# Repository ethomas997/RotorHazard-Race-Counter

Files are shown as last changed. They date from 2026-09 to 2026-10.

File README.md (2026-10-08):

# RotorHazard Race Counter

A battery-friendly ePaper sign that shows the current **heat** and **race number** at the flight line, so
pilots and spectators can always tell which race is up. Designed and built by RocketSled.

The display is a Seeed XIAO ESP32-C3 driving a 5.83" 648×480 monochrome ePaper panel in a 3D-printed
housing with two push-buttons (DN / UP). It can be run standalone from the buttons, or over WiFi from a
small built-in web page and HTTP API – or, given the address of a [RotorHazard](https://github.com/RotorHazard/RotorHazard)
timer, it follows the timer's current heat and round by itself.

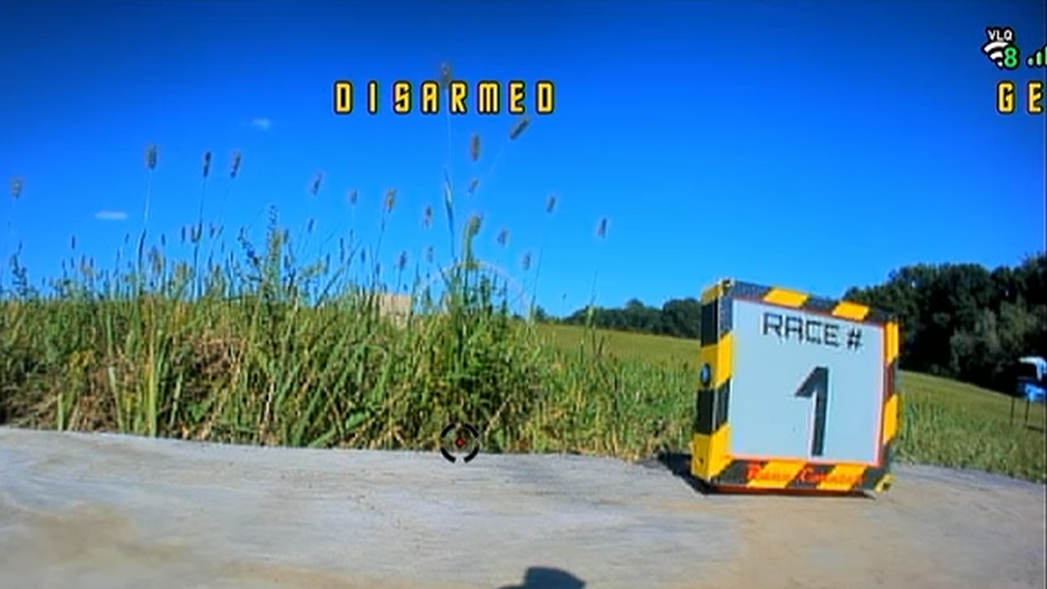
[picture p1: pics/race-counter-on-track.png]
Race Counter on the track


## Repository layout

| Path | Contents |
|---|---|
| `firmware/RaceCounter/` | Arduino sketch (RocketSled's V2.0 of Aug 9 2026, plus the fixes listed in `git log`), as modules: `RaceCounter.ino` (`setup`/`loop`), `RaceCounter.h` (config + shared state), `display.h/.cpp` (ePaper drawing), `web.h/.cpp` (web UI / HTTP API), `wifi_config.h/.cpp` (WiFi, setup AP, credentials, standalone mode), `buttons.h/.cpp`, `rh_client.h/.cpp` (follows a RotorHazard timer) |
| `firmware/RaceCounter/sketch.yaml` | Board / partition / option settings, read by arduino-cli and Arduino IDE 2.2+ |
| `firmware/RaceCounter/bg_png.h` | Web-page background image (RotorHazard logo) embedded as a byte array; regenerate with `tools/bin2header.py` |
| `firmware/RaceCounter/driver.h` | Seeed_GFX hardware selection (board + panel). **Required** – see Building |
| `firmware/libraries/` | Git submodules, pinned: `Seeed_GFX` (display), `WebSockets` (Socket.IO client), `ArduinoJson` |
| `docs/parts-list.md` | Bill of materials |
| `pics/` | Photos of the built unit and screenshots of the web pages |
| `stl/` | 3D-printed housing models (STL); see [Enclosure](#enclosure-3d-printing) |
| `assets/` | Source font (Orbitron Bold, OFL) and logo images used to generate the `.h` bitmaps |
| `tools/bin2header.py` | Turns a binary file into a `PROGMEM` C array header |

## Hardware

* Seeed Studio **XIAO ESP32-C3**
* Seeed **ePaper Driver Board for XIAO** (V2) – 24-pin FPC, JST battery input with charge IC
* **5.83" monochrome ePaper**, 648×480, UC8179 controller, 24-pin FPC
* Two momentary push-buttons to GND: **DN → D5**, **UP → D6** (internal pull-ups)
* 18650 Li-ion cell with a latching power button; USB-C pass-through port for charging and programming
* 3D-printed housing — STL files in [`stl/`](stl/) (see [Enclosure](#enclosure-3d-printing))

Full list with links: [docs/parts-list.md](docs/parts-list.md).

| Front | Inside |
|---|---|
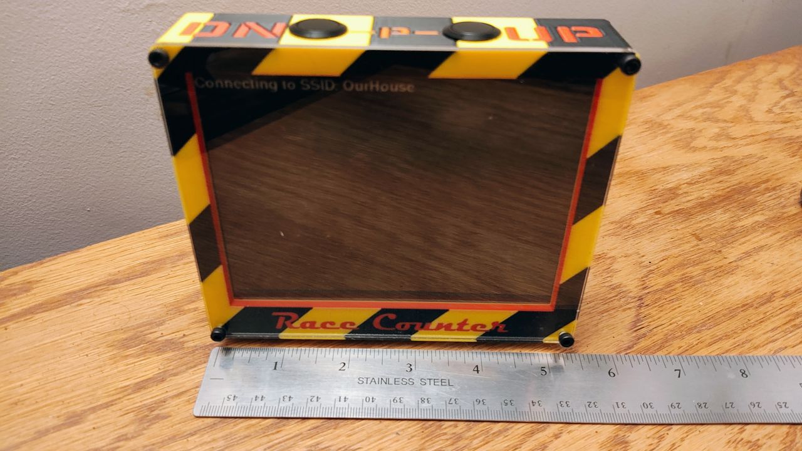
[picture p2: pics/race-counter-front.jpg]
Front
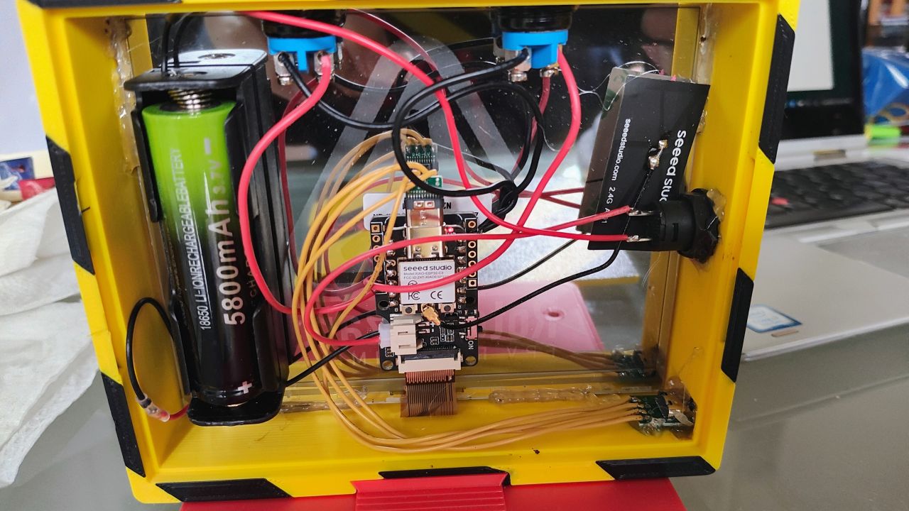
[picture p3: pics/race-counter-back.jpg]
Inside, back plate off
|  |  |

## Enclosure (3D printing)

The housing was designed by RocketSled. The STL files are in [`stl/`](stl/):

| File | Part |
|---|---|
| `Race Counter r2.stl` | Main body / front bezel |
| `Race Counter Back r3.stl` | Back cover |
| `Race Counter Base r2.stl` | Base / stand |

The geometry is split into sections so the unit can be printed in the colors shown in the photos, but
**the STLs do not carry any color information** — that is multi-material data specific to the printer, and
the colored-in version is only usable on a Bambu Lab H2C (multi-color) printer. On any other printer the
parts print in a single color; to reproduce the two-tone look you assign colors to the sections yourself in
your slicer.

## Building the firmware

RocketSled builds with Visual Studio + VisualMicro; the sketch also builds in the Arduino IDE 2.x and with
`arduino-cli`. Verified 2026-09-20 with `arduino-cli` 0.35.2, esp32 core 3.3.8, Seeed_GFX 2.0.3
(commit `0dfdd71`), WebSockets 2.7.3 and ArduinoJson 7.4.2:

```
Sketch uses 1510517 bytes (48%) of program storage space. Maximum is 3145728 bytes.
Global variables use 39152 bytes (11%) of dynamic memory.
```

The board and options are recorded in `firmware/RaceCounter/sketch.yaml`, which arduino-cli and Arduino
IDE 2.2+ pick up automatically, so the command line is just:

```bash
arduino-cli compile --libraries firmware/libraries firmware/RaceCounter
```

1. **Board package:** *esp32 by Espressif Systems* (RocketSled used 3.3.8; board-manager URL
   `https://espressif.github.io/arduino-esp32/package_esp32_index.json`). Board: **XIAO_ESP32C3**.
   * Partition Scheme: **Huge APP (3MB No OTA/1MB SPIFFS)** – the sketch filled 95 % of the default
     scheme's 1.2 MB app slot, and the device doesn't use OTA, so the larger no-OTA layout costs nothing.
     (RocketSled's units were flashed with the *Default 4MB* scheme; re-flashing with this one is fine – the
     partition table is rewritten as part of the upload.)
   * USB CDC On Boot: **Enabled**
2. **Libraries:** **[Seeed_GFX](https://github.com/Seeed-Studio/Seeed_GFX)** (display; not in the Arduino
   Library Manager), **[WebSockets](https://github.com/Links2004/arduinoWebSockets)** (Socket.IO client) and
   **[ArduinoJson](https://arduinojson.org/)** are vendored as git submodules under `firmware/libraries/`,
   pinned to versions known to build. Get them with
   ```bash
   git submodule update --init
   ```
   (or clone with `--recurse-submodules`). Then make them visible to the Arduino IDE by linking or copying
   each into your sketchbook's `libraries` folder – on Windows a directory junction avoids a second copy:
   ```
   mklink /J "<sketchbook>\libraries\Seeed_GFX" "<repo>\firmware\libraries\Seeed_GFX"
   ```
   (and likewise for `WebSockets` and `ArduinoJson`). `arduino-cli` users can skip the links and pass
   `--libraries firmware/libraries` instead.

   Seeed_GFX is a fork of TFT_eSPI and **conflicts with TFT_eSPI / Adafruit_GFX – remove those from your
   `libraries` folder first.** The sketch will still compile against the wrong library, it just won't drive
   the panel.
3. **`driver.h`** must be in the sketch folder (it is). Seeed_GFX picks it up automatically:
   ```c
   #define BOARD_SCREEN_COMBO 503   // 5.83 inch monochrome ePaper (UC8179), 648x480
   #define USE_XIAO_EPAPER_DRIVER_BOARD
   ```
   If you change the panel or carrier board, regenerate this with Seeed's configuration tool.
4. Compile and upload the sketch over USB-C. That's it – there is no separate filesystem image to upload;
   the web page's background image is compiled into the firmware (`bg_png.h`).

All other libraries (`WiFi`, `WebServer`, `HTTPClient`, `Preferences`) ship with the esp32 core.

## Operation

### First power-up / WiFi setup

* With no saved credentials the device starts an open access point **`RaceCounter-Setup`** and shows the AP
  IP (`192.168.4.1`) and MAC on the panel. Connect to it, open `http://192.168.4.1`, enter your SSID and
  password, *Save & Reboot*.
* It then connects to that network, shows the IP it was given and its MAC for a few seconds, and displays
  the RotorHazard splash screen. The web interface is at `http://<ip>/`.
* Every startup / status text screen has the name and firmware version on its first line.
* The MAC shown on both the AP screen and the "Connected" screen is the station MAC – the one your router
  sees – so it can be used directly for a static DHCP lease.

### Buttons

| Action | Result | Timing |
|---|---|---|
| UP | race number +1 (1…99, wraps) | Acts the moment the button is released, or after 0.25 s if it is held. Keep holding and it keeps stepping, one step per panel refresh (every 2–4 s). |
| DN | race number −1 (1…99, wraps) | Same as UP. Does nothing while the splash screen is showing. |
| UP or DN on a PRACTICE screen | leave practice: the big-"P" screen goes back to the race count, the "PRACTICE over a round number" screen switches its banner to "RACE #" – the number is not changed either way | |
| UP + DN together (short), in normal operation | toggle **PRACTICE** mode | The second button must go down within 0.25 s of the first; acts when either is released (before 3 s). |
| UP + DN **held for 3 s** | show the **information screen**: mode, SSID, IP, web address, signal, MAC, what was being shown, uptime, free memory | Acts at 3 s while both are still down. Any button press on the information screen goes back to the previous screen (splash / race count / practice) without changing anything. |
| UP + DN held at power-on | erase saved WiFi credentials and standalone flag, restart into AP mode | The pins are read **once**, about 2–3 s after power-on. Hold both before switching on, keep holding until "Old SSID and password deleted…" appears, then release. |
| UP + DN while "Connecting to SSID…" | same – use this if it is stuck on a network it can't reach | Checked every 0.3 s while connecting; any simultaneous press of ≥ 0.3 s works. |
| UP + DN while in AP mode | short: enable **standalone mode** (no WiFi, buttons only) and restart; long: information screen | Same detection as above. To leave standalone mode, use the power-on hold. |

Heat number can only be set from the web interface / HTTP API.

### Web interface

The main page shows what the panel is currently displaying, and has −/+ and *Set* controls for Heat and Race,
a *Practice* toggle, *Reset*, and *Refresh* (re-reads the current state from the counter), with the firmware
version at the bottom. The 🛠 icon
top-right opens the settings page where the SSID/password can be changed (*Update*) or erased (*Clear*);
both reboot the device. The settings page also has the **RotorHazard** server field (below) and shows the MAC
address and firmware version (`FW_VERSION` in `RaceCounter.h`, also printed in the serial banner at boot).

| Main page | Settings page |
|---|---|
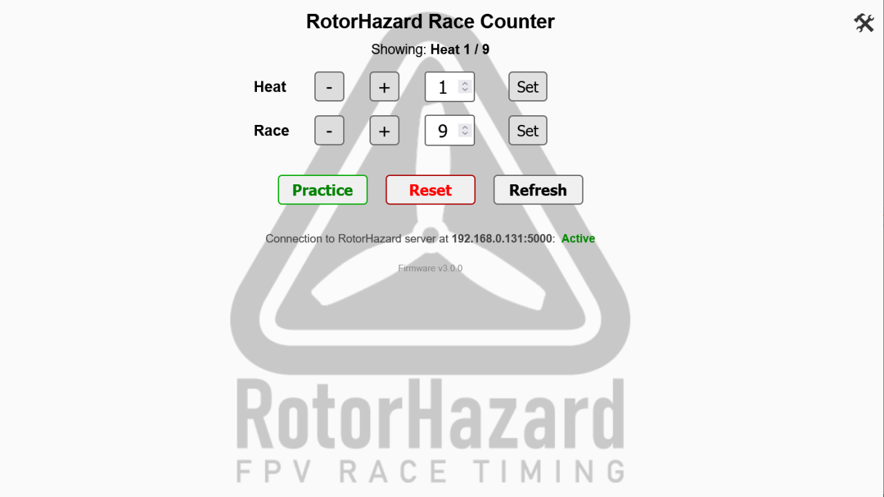
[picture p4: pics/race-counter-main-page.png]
Main page
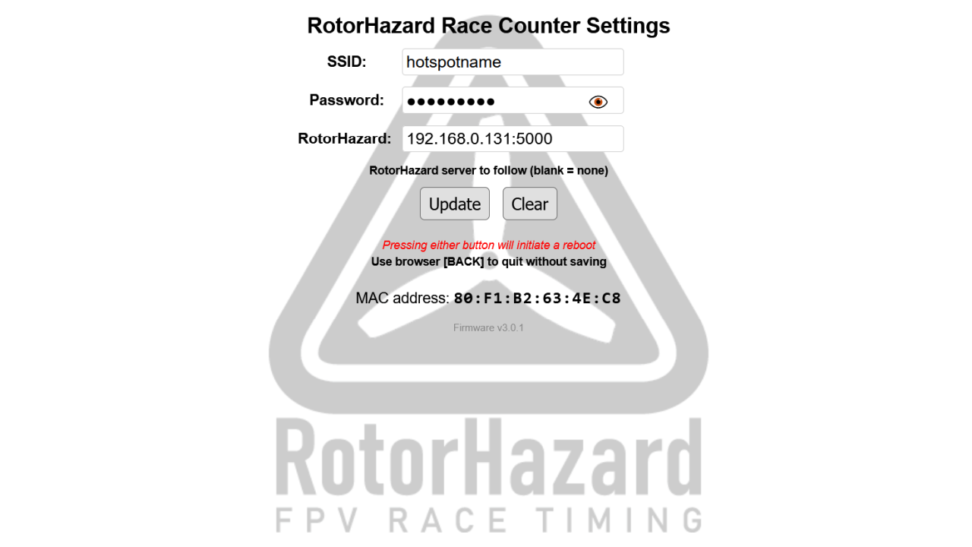
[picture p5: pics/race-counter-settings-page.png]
Settings page
|  |  |

### Following a RotorHazard timer

Enter the timer's address in the **RotorHazard** field on the settings page – `host` or `host:port`
(`192.168.1.10`, `rotorhazard.local:5000`; the port defaults to 5000) – and *Update*. Leave it blank to
turn this off. Nothing needs to be installed or configured on the timer; RotorHazard 4.1 or later.

The counter then connects to the server as a Socket.IO client, the same way a browser page does, and:

* asks for the current state (`load_data`), then listens to the `race_status` / `current_heat` broadcasts
  the server sends whenever a race is staged, started, stopped or saved, or the heat is changed;
* takes the heat id and `next_round` from them – the round that is being run or about to be run. Heat and
  race-format names come over the socket too (`heat_list` / `format_data` on connect, `heat_data` when a heat
  is renamed), with `GET /api/heat/<id>` / `/api/format/<id>` as the fallback for anything not in those lists;
  if the lists are too large for the counter's WebSocket library (over 15 KB – a very big event) it switches
  to the `/api` lookups for the rest of the session (`/status` → `rh.names_from`);
* shows the heat name as the banner and `next_round` as the big number – or `next_round + 1` once a race has
  been stopped but not yet saved, so the next race is announced right away. Heat 0 on the timer (no heat
  selected, "Practice Mode") shows the PRACTICE screen with the big "P"; a real heat run with a practice race
  format (any format whose name contains "practice", such as the stock "Open Practice") shows "PRACTICE" as
  the banner with the round number below it. Whenever the banner is anything other than "RACE #", a
  vertical "ROUND" label is drawn to the left of the number (for numbers below 20 – wider ones fill the
  panel). The panel only refreshes when something actually changed.

The buttons and web page keep working as manual overrides; the next event from the timer wins.

The link is supervised: the timer broadcasts a heartbeat every 0.5 s, and if nothing at all arrives for 10 s
the connection is treated as **lost** – a warning triangle appears in the top-right corner of the panel,
the main web page shows *Connection to RotorHazard server at host:port: Lost* in red (*Active* otherwise),
and the counter forces a reconnect. It clears itself as soon as traffic resumes. The state is also on the
information screen (hold both buttons) and in `/status` (`rh.state`: `active` / `lost`).
The results broadcast the timer sends after each saved race is bigger than the WebSocket library accepts,
so the connection drops and reconnects a few seconds later at that point; the state is re-requested on
every connect, so nothing is missed.

### HTTP API

Every endpoint except `/reset` is a plain `GET`, changes the display, and replies `303 → /` (so a browser
lands back on the main page). Scripts should send `allow_redirects=False` or just ignore the redirect.

| Endpoint | Effect |
|---|---|
| `/heatInc`, `/heatDec` | heat ±1 (0…99, wraps); race resets to 1 |
| `/heatSet?v1=N` | set heat to N (0–99). Heat 0 hides the heat number; banner shows "RACE #". Nonzero heat shows "Heat N" and resets race to 1 |
| `/raceInc`, `/raceDec` | race ±1 (1…99, wraps) |
| `/raceSet?v2=N` | set race to N (1–99) |
| `/practice` | **toggle** practice mode (banner "PRACTICE", big "P") |
| `/splash` | heat 0, race 0, practice off, show the RotorHazard splash screen (this is the web *Reset* button) |
| `/settings` | WiFi settings page |
| `/reset` (`POST` only) | **erases the saved WiFi credentials** and reboots into AP mode (the settings-page *Clear* button, behind a confirmation) |
| `/bg.png` | the web page background image |
| `/status` | **read-only** JSON: `name`, `version`, `mode` (`wifi` / `ap` / `standalone`), `ssid`, `ip`, `rssi`, `mac`, `heat`, `race`, `practice`, `banner`, `screen` (`splash` / `counter` / `practice` / `info` / `ap_setup` / `status`), `rh` (`server`, `state`, `heat_id`, `round`, `heat_name`, `names_from`), `uptime_s`, `free_heap`. Also available in AP mode. |

Out-of-range values are ignored.

## Known issues / roadmap

The sketch is RocketSled's V2.0 plus a series of small fixes, each its own commit – see `git log`. The
first import commit holds the code exactly as received. Note for anyone building from that original: the
Arduino build system matches include names to libraries case-sensitively even on Windows, so
`<webserver.h>` / `<preferences.h>` had to become `WebServer.h` / `Preferences.h` (VisualMicro is more
forgiving).

Remaining items:

* The WiFi connect loop never times out (the only escape is holding both buttons).

## Credits

Hardware, housing and firmware by RocketSled. Orbitron font by Matt McInerney, SIL Open Font License.

## License

[MIT](LICENSE). The RotorHazard name and logo are copyright Michael Niggel/Hazard Creative, LLC and are used
under the RotorHazard project's own terms (see the note in `LICENSE`); they are not covered by the MIT license.

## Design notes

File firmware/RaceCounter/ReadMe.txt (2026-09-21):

Start Up:

if both buttons are pressed
	clear Standalone Mode
	clear SSID and WiFi password
	Restart - device comes up in AP mode to allow WiFi setup

if Standalone Mode is set
	Device skips WiFi connection and web server setup
	Go to Operation Mode - controlled via buttons only, no web interface

if there are no saved WiFi credentials
	Device will come up in WiFI AP mode serving SSID "RaceCounter-Setup" (No password is required to connect)
	Serves a web page at http://192.168.4.1 where SSID and password can be set
		When the SSID and password are submitted, they are saved 
		restart

	if both buttons are pressed (while in AP mode)
		set standalone mode
		restart

else
	Device will attempt to connect to the saved WiFi SSID using the saved password
	while attempting to connect, if both buttons are pressed 
		clear WiFi credentials and standalone mode (which isn't actually set in this case, but just to be sure)
		restart
	When connection is made, start web server and go to Operation Mode

Operation Mode:

RotorHazard splash screen is displayed and the device waits for input

Pushing a button will increment/decrement the race # by 1 - minimum number is 1, maximum is 99, race # will wrap

Pushing both buttons at the same time will switch to PRACTICE mode
Pushing both buttons again will switch back to displaying the last race number

if a WiFi connection has been established, the device can also be controlled via the web interface at the assigned IP address (displayed for a few seconds when connection is successful)

Web interface has a settings page that can be accessed by clicking the tool icon in the upper right corner of the page
	The settings page allows the SSID and password to be cleared or changed to a new value
	Pushing either button will initiate a restart
	Use browser back button to return to the main page without making changes

Note the web server isn't all that responsive, give it a few seconds to update after clicking something, pay attention to the browser's loading indicator
Note that HEAT # can only be controlled via the web interface, it cannot be displayed using the buttons

The current race number is always displayed in large font on the lower part of the screen - minimum number is 1, maximum is 99, count will wrap

If HEAT is nonzero, the header line on the display will show "HEAT # NN" (where NN is the heat # set via the web interface)

If HEAT has not been set, or is reest to zero (via web interface), the display header line will show "RACE #" only (no heat number)

The + and - buttons increment/decrement their respective counts by 1
Numbers can be entered directly in the input box, clicking SET or hitting enter will commit the change and update the display accordingly
Race cannot be set to 0, Heat can
Maximum is 99 for both

The PRACTICE button toggles practice mode on and off - button turns green when practice mode is active
	When practice mode is active, the display header will show "PRACTICE" and the the letter "P" will be displayed below the header 

The RESET button will reset race # to 1, heat to 0, turn off practice mode, and update the display to show the RotorHazard splash screen

See RaceCounterMainPage.png and RaceCounterSettingsPage.png for web page images

Note: Uses SPIFFS to store the web background image - BG.PNG must be loaded to the root directory of the SPIFFS partition. If the image is not found, system will still work but the web page background will just be white.

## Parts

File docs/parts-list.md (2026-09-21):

# Parts list

## Electronics

| Qty | Part | Notes |
|---|---|---|
| 1 | [Seeed Studio XIAO ESP32-C3](https://www.seeedstudio.com/Seeed-XIAO-ESP32C3-p-5431.html) | Male headers required to plug into the driver board – use the [pre-soldered](https://www.seeedstudio.com/Seeed-Studio-XIAO-ESP32C3-Pre-Soldered-p-6331.html) variant or solder your own. Includes the 2.4 GHz FPC antenna with U.FL lead, which is used as-is (stuck to the inside wall of the case). |
| 1 | [Seeed ePaper Driver Board for XIAO (V2)](https://www.seeedstudio.com/ePaper-breakout-Board-for-XIAO-V2-p-6374.html) | 24-pin FPC connector, JST 2-pin `BAT` input with `ON/OFF` switch, built-in charge IC. |
| 1 | [5.83" monochrome ePaper display, 648×480](https://www.seeedstudio.com/5-83-Monochrome-ePaper-Display-with-648x480-Pixels-p-5785.html) | UC8179 controller, 24-pin FPC. Any UC8179 648×480 24-pin panel (e.g. GoodDisplay GDEY0583T81) is electrically equivalent. |
| 2 | Panel-mount momentary push-button, black domed cap, blue threaded body, solder-tab terminals | DN and UP, through the top of the case. Wired to GND: DN → D5, UP → D6. |
| 1 | Panel-mount latching (push-on / push-off) push-button, black | Power switch, right side of the case. In series with the battery + lead to the driver board's `BAT` input. |
| 1 | 18650 Li-ion cell, 3.7 V | Fitted cell is labelled "5800 mAh"; realistic capacity for an 18650 is 2000–3000 mAh. ≈ 25 mA draw with WiFi off. Charged through the driver board's charge IC whenever USB is connected. |
| 1 | 18650 single-cell holder with wire leads | Hot-glued to the left inside wall. |
| 1 | JST 2.0 mm 2-pin battery lead | Holder / power switch → driver board `BAT`. |
| 1 | USB-C male plug breakout board | Inserted into the XIAO's USB-C port. |
| 1 | USB-C female socket breakout board | Hot-glued at the bottom-right corner as the external charge / programming port; 4 wires (`GND`, `D-`, `D+`, `VBUS`) to the plug breakout. |
| — | Hook-up wire (24–26 AWG for buttons/power, 30 AWG wire-wrap for USB data), hot glue | |

## Mechanical

| Qty | Part | Notes |
|---|---|---|
| 1 | 3D-printed housing, ≈ 5.4" wide | Yellow body with black hazard stripes (two-colour print); "Race Counter" script and DN / UP labels. STLs to be added. |
| 1 | 3D-printed back plate, red | RotorHazard logo. |
| 1 | Clear front window | Striped bezel printed on / under it. |
| 4 | Black cap screws, front corners | |
| 2 | Rubber bumper feet, bottom edge | |

## Software & tools

* Arduino IDE 2.x, or Visual Studio + [VisualMicro](https://www.visualmicro.com/)
* esp32 Arduino core 3.3.x — board *XIAO_ESP32C3*, partition *Huge APP (3MB No OTA)*, *USB CDC On Boot: Enabled* (all recorded in `firmware/RaceCounter/sketch.yaml`)
* [Seeed_GFX](https://github.com/Seeed-Studio/Seeed_GFX) library (git submodule in `firmware/libraries/`; conflicts with TFT_eSPI / Adafruit_GFX)
* `driver.h` in the sketch folder (in the repo)
* Orbitron Bold TTF (`assets/fonts/`) + Adafruit `fontconvert`, for regenerating the `Orbitron*pt7b.h` headers
* `tools/bin2header.py`, for regenerating the embedded web-page background (`bg_png.h`)

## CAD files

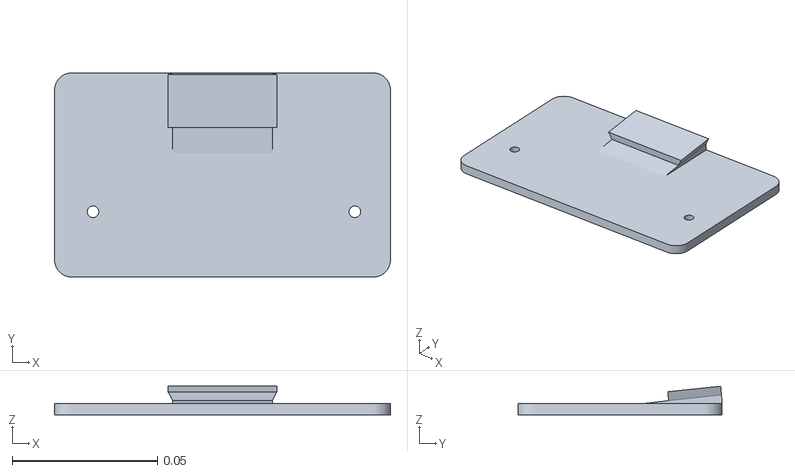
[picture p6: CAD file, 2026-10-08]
stl/Race Counter Base r2.stl
0.115 x 0.0702 x 0.00983

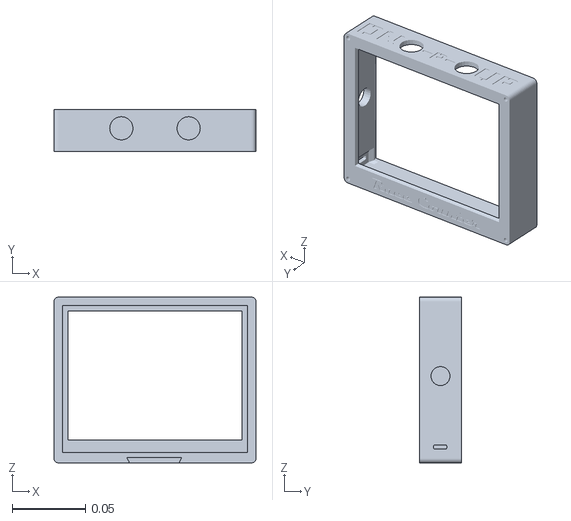
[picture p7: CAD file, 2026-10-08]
stl/Race Counter r2.stl
0.138 x 0.029 x 0.113

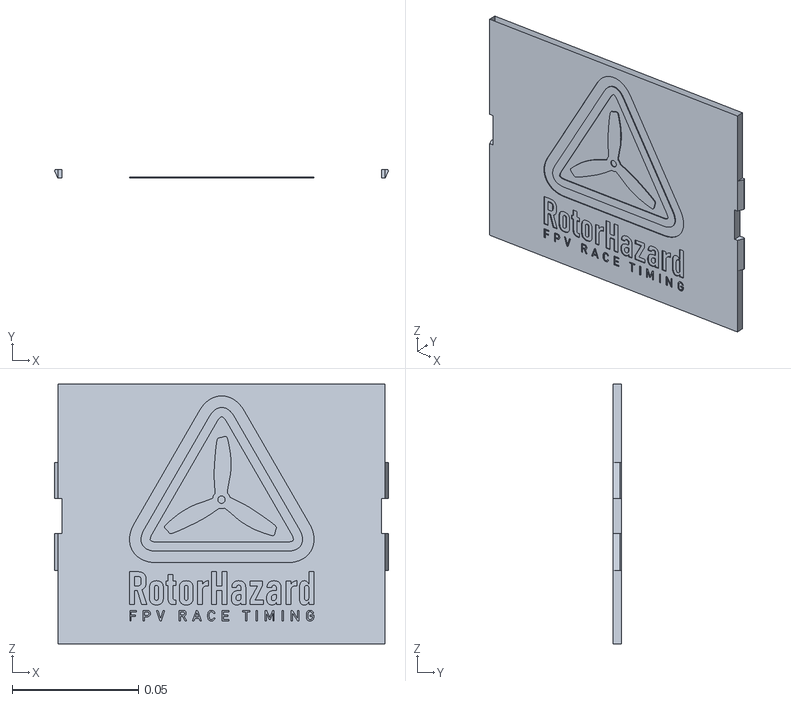
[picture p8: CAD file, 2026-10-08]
stl/Race Counter Back r3.stl
0.132 x 0.0036 x 0.103

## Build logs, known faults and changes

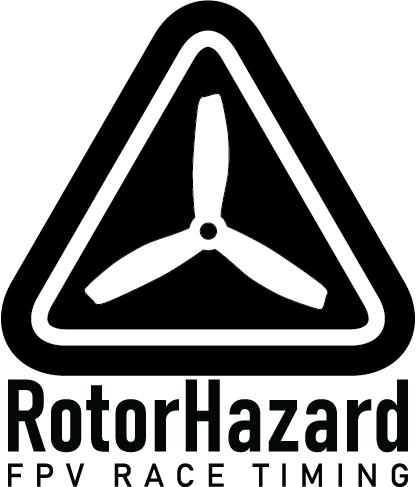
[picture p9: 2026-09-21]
assets/images/RotorHazard-Logo-416x487.png

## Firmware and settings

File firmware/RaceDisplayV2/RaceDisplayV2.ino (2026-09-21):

#include "Arduino.h"

#include <WiFi.h>
#include <WebServer.h>
#include <Preferences.h>
#include <esp_mac.h>


#include "TFT_eSPI.h"
#include "RotorHazardLogo.h"
#include "bg_png.h"
#include "Orbitron50pt7b.h"
#include "Orbitron68pt7b.h"

#define DNSWITCH    D5
#define UPSWITCH    D6

#define DISPLAYWIDTH 648
#define DISPLAYHEIGHT 480

#define BANNERFONT      Orbitron50pt7b
#define BANNERFONTSIZE  1
#define STATEFONT       Orbitron68pt7b
#define STATEFONTSIZE   3
#define HEATFONT        Orbitron50pt7b
#define HEATFONTSIZE    1

#define CENTERINGOFFSET -10     // the width of text returned by the library is saying the text is slightly wider than it actually is, so it doesn't center right. This compensates.

#define CONNECT_POLL_MS     300     // how often to check for a WiFi connection (and the both-buttons escape) while connecting
#define CONNECT_REFRESH_MS  10000   // how often to refresh the ePaper with progress dots while connecting

#define BUTTON_DEBOUNCE_MS  20      // a button reading has to hold this long before it counts (filters contact bounce)
#define BUTTON_COMBO_MS     250     // after one button goes down, how long to wait for the other before treating it as a single press

#ifdef EPAPER_ENABLE    // Only compile this code if EPAPER_ENABLE is defined (in User_Setup.h, typically part of the TFT_eSPI library 
                        // Except..., the HW used for this display requires the Seeed_GFX library, a fork of the Adafruit_GFX library, which replaces the TFT_eSPI library 
						// You have to remove the Adafruit_GFX library and replace it with the Seeed_GFX library, since the Seeed library emulates the Adafruit library but adds extra functionality for the ePaper display.
EPaper epaper;
#endif

WebServer   server(80);

uint8_t raceCount;
bool    practiceMode;
bool	inAPMode;
bool    standAloneMode;

uint8_t heatCount = 0;

Preferences prefs;

String ssidStored = "";
String passStored = "";
String standAlone = "";

struct Button {                     // see handleButtons(); declared up here so the IDE's auto-generated prototypes can see it
    uint8_t         pin;
    bool            pressed;        // debounced state
    bool            lastRaw;        // last raw reading
    unsigned long   changedAt;      // when the raw reading last changed
};

Button upButton = { UPSWITCH, false, false, 0 };
Button dnButton = { DNSWITCH, false, false, 0 };


//////////////////////////////////////////////////////////////////////////////
//
// Handler for the Practice button. Toggles practice mode on and off. In practice mode, the display shows "PRACTICE" at the top and "P" at the bottom. 
//

void doPractice() {

    uint16_t    W, H;

    char    charBuff[128];

    practiceMode = !practiceMode;

    if (practiceMode == false ) {
        if (raceCount == 0)
            raceCount = 1;
        doRaceCount();
        return;
    }

    epaper.fillScreen(TFT_WHITE);
    epaper.setFreeFont(&BANNERFONT);
    epaper.setTextSize(BANNERFONTSIZE);
    H = epaper.fontHeight();

    sprintf(charBuff, "PRACTICE");
    W = epaper.textWidth(charBuff);

    epaper.setCursor((DISPLAYWIDTH - W) / 2, H);              // center top
    epaper.print(charBuff);

    epaper.setFreeFont(&STATEFONT);
    epaper.setTextSize(STATEFONTSIZE);

    W = epaper.textWidth("P");
    H = epaper.fontHeight();

    epaper.setCursor((DISPLAYWIDTH - W) / 2, DISPLAYHEIGHT - 20);        // center bottom
    epaper.printf("P");

    epaper.update();
}


//////////////////////////////////////////////////////////////////////////////
//
// handler for displaying the race count.
//


void    doRaceCount() {
    uint16_t    W, H;

    char        charBuff[128];

    practiceMode = false;

    epaper.fillScreen(TFT_WHITE);
    epaper.setFreeFont(&BANNERFONT);
    epaper.setTextSize(BANNERFONTSIZE);
    H = epaper.fontHeight();

    if (heatCount == 0) {
        epaper.setFreeFont(&BANNERFONT);
        epaper.setTextSize(BANNERFONTSIZE);
        H = epaper.fontHeight();

        sprintf(charBuff, "RACE #");
    }
    else {
        epaper.setFreeFont(&HEATFONT);
        epaper.setTextSize(HEATFONTSIZE);
        H = epaper.fontHeight();

        sprintf(charBuff, "Heat %d", heatCount);
    }

    W = epaper.textWidth(charBuff);
    epaper.setCursor((DISPLAYWIDTH - W) / 2, H);              // center top
    epaper.print(charBuff);

    epaper.setFreeFont(&STATEFONT);
    epaper.setTextSize(STATEFONTSIZE);

    sprintf(charBuff, "%d", raceCount);
    W = epaper.textWidth(charBuff);
    H = epaper.fontHeight();

    epaper.setCursor((DISPLAYWIDTH - W) / 2 + CENTERINGOFFSET, DISPLAYHEIGHT - 20);        // center bottom
    epaper.printf("%s", charBuff);

    epaper.update();
}


//////////////////////////////////////////////////////////////////////////////
//
// handler for displaying the RotorHazard spalsh screen
//

void doWelcomeScreen() {
    epaper.fillScreen(TFT_WHITE);
    epaper.drawBitmap((DISPLAYWIDTH - LOGOWIDTH) / 2, (DISPLAYHEIGHT - LOGOHEIGHT) / 2, RotorHazardLogo, LOGOWIDTH, LOGOHEIGHT, TFT_WHITE, TFT_BLACK);
    epaper.update();
}


//////////////////////////////////////////////////////////////////////////////
//
// Generate the HTML for the main page, which includes the current heat and race count and buttons to increment/decrement/set them, as well as the Practice and Reset buttons.
//

String handleMainPage() {
    String page = "<!DOCTYPE html><html><head><meta name='viewport' content='width=device-width, initial-scale=1'>";

    page += "<style>";

    page += "body{font-family:sans-serif;margin:0;padding:0;background:#fafafa;background:url('/bg.bmp') no-repeat center center fixed;background-size:cover;}";
    page += ".main-container{max-width:480px;min-height:320px;margin:0 auto;padding:10px;}";

    /* Headings */
    page += "h1{font-size:26px;margin:8px 0 12px 0;font-weight:bold;text-align:center;}";
    page += "h2{font-size:20px;margin:4px 0;font-weight:bold;}";
    page += "h3{font-size:18px;margin:4px 0;font-weight:bold;}";
    page += "h4{font-size:16px;margin:3px 0;font-weight:bold;}";

    /* Table layout */
    page += "table{border-collapse:collapse;width:100%;}";
    page += "td{padding:4px;height:50px;vertical-align:middle;}";

    /* Column widths */
    page += "col.inputcol{width:60px;}";
    page += "col.setcol{width:100px;}";
    page += "col.smallcol{width:50px;}";
    page += "col.textcol{width:40px;}";

    /* Inputs */
    page += "input{font-size:24px;width:60px;height:34px;text-align:center;margin:2px;padding:2px;border:2px solid #666;border-radius:4px;}";

    /* Buttons */
    page += "button{font-size:20px;height:40px;margin:2px;padding:0 10px;border-radius:6px;border:2px solid #666;background:#e0e0e0;}";
    page += "button:active{background:#ccc;}";

    /* Increment/Decrement buttons */
    page += ".incdec{width:40px;height:40px;font-size:24px;border-radius:6px;border:2px solid #666;display:flex;justify-content:center;align-items:center;background:#ddd;}";

    /* Practice button states */
    page += ".practiceOn{width:120px;background:#00ff00;color:black;border:2px solid #666;}";
    page += ".practiceOff{width:120px;color:green;font-weight:600;background:#f0f0f0;border:2px solid #0a0;}";
    page += ".resetBut{width:120px;color:red;font-weight:600;background:#f0f0f0;border:2px solid #a00;}";

    /* Bottom button row */
    page += ".bottomButtons{display:flex;gap:20px;justify-content:center;margin-top:10px;}";

    /* Settings icon */
    page += ".settingsIcon{position:fixed;top:10px;right:10px;font-size:32px;cursor:pointer;text-decoration:none;color:#333;}";

    page += ".bgImg{"
        "position:fixed;"
        "top:3%; left:3%;"
        "width:94%; height:94%;"
        "object-fit:contain;"
        "opacity:0.20;"      // adjust fade here
        "z-index:-1;"
        "}";

    page += "</style>";

    page += "</head>";

    page += "<body><img src='/bg.png' class='bgImg'><div class='main-container'>";

    page += "<a href='/settings' class='settingsIcon'>&#128736;</a>";

    page += "<h1>Race Count Display</h1>";

    page += "<table>";
    page += "<colgroup>";
    page += "<col class='textcol'>";
    page += "<col class='smallcol'>";
    page += "<col class='smallcol'>";
    page += "<col class='inputcol'>";
    page += "<col class='setcol'>";
    page += "</colgroup>";

    // -------- ROW 1: Value 1 --------
    page += "<tr>";
    page += "<td><h2>Heat </h2></td>";
    // Decrement button
    page += "<td>";
    page += "<button class='incdec' onclick=\"location.href='/heatDec'\">-</button>";
    page += "</td>";
    // Increment button
    page += "<td>";
    page += "<button class='incdec' onclick=\"location.href='/heatInc'\">+</button>";
    page += "</td>";
    // Value 1 input
    page += "<td>";
    page += "<form action='/heatSet' method='GET'>";

    if (heatCount)
        page += "<input type='number' name='v1' min='0' max='99' value='" + String(heatCount) + "'>";
    else
        page += "<input type='text' value='None' readonly>";

    page += "</td>";
    // Set Value 1 button
    page += "<td>";
    page += "<button type='submit'>Set</button>";
    page += "</form>";
    page += "</td>";
    page += "</tr>";

    // -------- ROW 2: Value 2 --------
    page += "<tr>";
    page += "<td><h2>Race </h2></td>";
    // Decrement button
    page += "<td>";
    page += "<button class='incdec' onclick=\"location.href='/raceDec'\">-</button>";
    page += "</td>";
    // Increment button
    page += "<td>";
    page += "<button class='incdec' onclick=\"location.href='/raceInc'\">+</button>";
    page += "</td>";
    // Value 2 input
    page += "<td>";
    page += "<form action='/raceSet' method='GET'>";
    if (raceCount)
        page += "<input type='number' name='v2' min='1' max='99' value='" + String(raceCount) + "'>";
    else
        page += "<input type='text' value='None' readonly>";

    page += "</td>";
    // Set Value 2 button
    page += "<td>";
    page += "<button type='submit'>Set</button>";
    page += "</form>";
    page += "</td>";
    page += "</tr>";
    page += "</table><br>";

    // Other buttons

    String practiceClass = practiceMode ? "practiceOn" : "practiceOff";

    page += "<div class='bottomButtons'>";
    page += "<button class='" + practiceClass + "' onclick=\"location.href='/practice'\">Practice</button>";
    page += "<button class='resetBut' onclick=\"location.href='/splash'\">Reset</button>";
    page += "</div>";
    page += "<br>";

    page += "</div></body></html>";


    return page;
}


//////////////////////////////////////////////////////////////////////////////
//
// Handle HTML requests for the main page, which shows the current heat and race count stuff, and buttons to change them, as well as the Practice and Reset buttons.
//

void handleRoot() {
    server.send(200, "text/html", handleMainPage());
}


//////////////////////////////////////////////////////////////////////////////
//
// ESP32 leaves the string for the item that was clicked in the browser address bar, so refresh makes it do the same thing again
// Calling this routine at the end of each response throws the browser back to the root page again
//

void handleBackToRoot() {
    server.sendHeader("Location", "/");
    server.send(303);
}


//////////////////////////////////////////////////////////////////////////////
//
// the Race # increment button
//

void handleIncrementRace() {
    raceCount = (raceCount + 1) % 100;   // keep 2‑digit wraparound

    if (raceCount == 0)
        raceCount = 1;

    handleBackToRoot();
    doRaceCount();
}


//////////////////////////////////////////////////////////////////////////////
//
// the Race # decrement button
//

void handleDecrementRace() {
    raceCount = (raceCount - 1 + 100) % 100;

    if (raceCount == 0)
        raceCount = 1;

    handleBackToRoot();
    doRaceCount();
}


//////////////////////////////////////////////////////////////////////////////
//
// the Heat # increment button.
//

void handleIncrementHeat() {
    heatCount = (heatCount + 1) % 100;   // keep 2‑digit wraparound
    raceCount = 1;

    handleBackToRoot();
    doRaceCount();
}


//////////////////////////////////////////////////////////////////////////////
//
// the Heat # decrement button.
//

void handleDecrementHeat() {
    heatCount = (heatCount - 1 + 100) % 100;
    raceCount = 1;

    handleBackToRoot();
    doRaceCount();
}


//////////////////////////////////////////////////////////////////////////////
//
// the Practice button.
//

void handlePractice() {
    handleBackToRoot();
    doPractice();
}


//////////////////////////////////////////////////////////////////////////////
//
// the settings page "Clear" button (POST /reset). This clears the stored WiFi SSID and password, shows a message on the display, and restarts the device after a delay.
//

void handleReset() {

    int16_t H;

    prefs.begin("wifi", false);
    prefs.remove("ssid");
    prefs.remove("pass");
    prefs.end();

    server.send(200, "text/html", "<html><body style='font-family:sans-serif;'><h2>WiFi credentials cleared.<br>Rebooting into setup mode...</h2></body></html>");

    epaper.fillScreen(TFT_WHITE);
    epaper.setFreeFont(&FreeSansBold12pt7b);    // last font used was probably the big race-number font
    epaper.setTextSize(1);
    H = epaper.fontHeight();
    epaper.setCursor(0, H);              // center top
    epaper.print("Old SSID and password deleted\nRestarting in 5 seconds...");
    epaper.update();
    delay(5000);

    heatCount = 0;
    raceCount = 1;
    practiceMode = false;

    ESP.restart();
}


//////////////////////////////////////////////////////////////////////////////
//
// this handles the RESET button on the main page, which resets heat and race and practice and then throws the splash screen up again.
//

void handleSplash() {
    handleBackToRoot();
    heatCount = 0;
    raceCount = 0;
    practiceMode = false;
    doWelcomeScreen();
}


//////////////////////////////////////////////////////////////////////////////
//
// the Set Heat button. This looks for a number in the input box, and if it's valid, it sets the heat count to that number. 
// If it's not valid, it leaves it unchanged. 
// If you click Set when the heat count is currently zero ("None" displayed in the input box), it sets it to 1. 
// If you enter an out of range value, it is ignored.
//

void handleSetHeat() {      // can't enter a number in the box after startup, set to readonly, it says "None". Clicking SET advances it to 1 and sets it to changeable

    handleBackToRoot();

    int v = 1;              // if you click SET and race number has not already been set, it sets race number to 1. If you enter an out of range value, it is ignored.

    if (server.hasArg("v1")) {
        v = server.arg("v1").toInt();
        if (v < 0 || v > 99)
            v = heatCount;
        }
    
    heatCount = v;

    if(heatCount)
        raceCount = 1;

    practiceMode = false;
    doRaceCount();
}


//////////////////////////////////////////////////////////////////////////////
//
// the Set Race button. This looks for a number in the input box, and if it's valid, it sets the race count to that number. 
// If it's not valid, it leaves it unchanged. If you click Set when the race count is currently zero ("None" displayed in the input box), it sets it to 1. 
// If you enter an out of range value, it is ignored.
//

void handleSetRace() {      // same functionality as above, but for the set race input box. Difference here, heat is allowed to be zero.
    int v = 1;

    if (server.hasArg("v2")) {
        v = server.arg("v2").toInt();
        if (v < 1 || v > 99)
            v = raceCount;
    }

    raceCount = v;

    practiceMode = false;
    doRaceCount();

    handleBackToRoot();
}


//////////////////////////////////////////////////////////////////////////////
//
// This handler is only invoked when the device is in AP mode, which happens when there is no stored WiFi SSID and password. 
// It generates the HTML for the page that allows you to enter a WiFi SSID and password, and submit them to be saved in preferences.
//

void handleRootAP() {
    String page = "<!DOCTYPE html><html><body style='font-family:sans-serif;'><head>";
    page += "<meta name='viewport' content='width=device-width, initial-scale=1, maximum-scale=1, user-scalable=no'>";
    page += "<style>";
    page += "h1{font-size:26px;margin:8px 0 12px 0;font-weight:bold;}";
    page += "h2{font-size:20px;margin:4px 0;font-weight:bold;}";
    page += "h3{font-size:18px;margin:4px 0;font-weight:bold;}";
    page += "h4{font-size:16px;margin:3px 0;font-weight:bold;}";
    
    page += "button{font-size:20px;height:40px;margin:2px;padding:0 10px;border-radius:6px;border:1px solid #666;background:#e0e0e0;}";
    page += "button:active{background:#ccc;}";

    page += "</style>";

    page += "<h2>Race Count Display WiFi Setup</h2>";
    page += "<form action='/save' method='POST'>";
    page += "SSID:<br><input name='ssid'><br><br>";
    page += "Password:<br><input name='pass' type='password'><br><br>";
    page += "<button type='submit'>Save & Reboot</button>";
    page += "</form><br>Push both buttons to set standalone mode</body></html>";
    server.send(200, "text/html", page);
}


//////////////////////////////////////////////////////////////////////////////
//
// This handler is only invoked when the device is in AP mode, which happens when there is no stored WiFi SSID and password.
// It handles the saving of the SSID and password entered by the user on the RootAP page.
// It checks that both SSID and password are provided, saves them in preferences, shows a confirmation message, and restarts the device after a short delay.
//

void handleSaveAP() {
    if (server.hasArg("ssid") && server.hasArg("pass")) {
        String ssid = server.arg("ssid");
        String pass = server.arg("pass");

        prefs.begin("wifi", false);
        prefs.putString("ssid", ssid);
        prefs.putString("pass", pass);
        prefs.end();

        String message = "<html><body><h2>";
        message += "new SSID: ";
        message += ssid;
        message += "<br>PWD is: ";
        message += pass;
        message += "<br><br>Saved!<br>Rebooting...</h2></body></html>";

        server.send(200, "text/html", message);

        delay(1500);
        ESP.restart();
    }
    else {
        server.send(400, "text/plain", "Missing SSID or password");
    }
}
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
void loop()
{
    server.handleClient();
    handleButtons();
}


//////////////////////////////////////////////////////////////////////////////
//
// Button handling.
//
// Presses are edge-triggered: one press is one action, and holding a button does not repeat. A single button
// acts as soon as it is released, or as soon as it has been held for BUTTON_COMBO_MS, whichever comes first -
// so a quick tap responds immediately instead of waiting out the combo window (and then being missed because
// the button was already up again). Both buttons down within BUTTON_COMBO_MS of each other is the
// both-buttons press, and it acts the moment the second one goes down. After any action nothing more happens
// until both buttons have been released.
//

// Returns the debounced state of a button (true = pressed, active low). A change in the raw reading has to
// hold for BUTTON_DEBOUNCE_MS before it counts, which filters contact bounce.

bool readButton(Button &b) {
    bool raw = (digitalRead(b.pin) == LOW);

    if (raw != b.lastRaw) {
        b.lastRaw = raw;
        b.changedAt = millis();
    }
    else if (raw != b.pressed && millis() - b.changedAt >= BUTTON_DEBOUNCE_MS) {
        b.pressed = raw;
    }
    return b.pressed;
}

void handleButtons() {
    static unsigned long    firstDownAt = 0;            // when the first button went down; 0 = nothing pending
    static bool             seenUp = false;             // buttons seen down since firstDownAt
    static bool             seenDn = false;
    static bool             waitForRelease = false;     // set after an action: ignore the buttons until both are up

    bool up = readButton(upButton);
    bool dn = readButton(dnButton);

    if (waitForRelease) {
        if (!up && !dn)
            waitForRelease = false;
        return;
    }

    if (firstDownAt == 0) {                             // nothing pending: has a press started?
        if (!up && !dn)
            return;
        firstDownAt = millis();
        seenUp = up;
        seenDn = dn;
    }
    else {
        seenUp |= up;
        seenDn |= dn;
    }

    bool combo    = seenUp && seenDn;
    bool released = !up && !dn;
    bool expired  = millis() - firstDownAt >= BUTTON_COMBO_MS;

    if (!combo && !released && !expired)
        return;                                         // still waiting to see whether this becomes a both-buttons press

    firstDownAt = 0;
    waitForRelease = true;

    if (combo) {
        if (inAPMode)
            setStandAlone();                            // in AP mode both buttons turn on standalone mode - this will force a restart
        else
            doPractice();
    }
    else if (inAPMode) {
        // single buttons do nothing in AP mode
    }
    else if (seenUp) {
        Serial.println("Up Switch pressed!");

        if (++raceCount == 100)
            raceCount = 1;
        doRaceCount();
    }
    else if (raceCount != 0) {                          // Down does nothing while the splash screen is showing (race count 0)
        Serial.println("Down Switch pressed!");

        if (--raceCount == 0)
            raceCount = 99;
        doRaceCount();
    }
}

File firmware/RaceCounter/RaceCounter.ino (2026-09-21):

//////////////////////////////////////////////////////////////////////////////
//
// RotorHazard Race Counter - ePaper heat / race number display for the flight line.
// Hardware, housing and original firmware by RocketSled. See README.md and RaceCounter.h for the source layout.
//
//////////////////////////////////////////////////////////////////////////////

#include "RaceCounter.h"
#include "display.h"
#include "web.h"
#include "wifi_config.h"
#include "buttons.h"
#include "rh_client.h"

// Shared race state (declared in RaceCounter.h)

uint8_t raceCount = 0;
uint8_t heatCount = 0;
bool    practiceMode = false;
String  bannerText = "";


//////////////////////////////////////////////////////////////////////////////
//
// Setup
//

void setup()
{
    Serial.begin(115200);

    delay(2000);

    Serial.printf("\n\n\n------" PAGE_TITLE " v" FW_VERSION "-----\n");

    initButtons();

    epaper.begin();

    checkClearAll();                        // check if both buttons are pressed on startup, if so, does not return, clears WiFi credentials and restarts
                                            // which then comes back through setup again, but with cleared credentials 

    loadSettings();

    if (standAlone == "TRUE") {
        Serial.println("Standalone mode enabled, skipping WiFi setup");
        startStatusScreen();
        epaper.print("\nStandalone mode enabled.\nNo WiFi needed to operate.\nPush both buttons on startup\nto clear this setting.\n");
        epaper.update();
        delay(2500);
        standAloneMode = true;
        updateDisplay();
        return;                             // skip all the WiFi stuff and just start the display for manual use only
    }

    if (ssidStored == "") {                 // go to AP mode instead of trying to connect to WiFi
        inAPMode = true;                    // in AP mode the buttons only set standalone mode or show the information screen
        startConfigAP();                    // (draws the setup screen)
        return;
    }

    inAPMode = false;

    connectToWiFi();
    startWebServer();
    rhBegin();

    delay(2000);

    updateDisplay();
}


//////////////////////////////////////////////////////////////////////////////
//
// Main loop
//

void loop()
{
    server.handleClient();
    rhLoop();
    handleButtons();
}

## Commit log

2026-09-21 Fix include name case so the sketch builds with arduino-cli / Arduino IDE
    [RaceDisplayV2.ino]
2026-09-21 Select a readable font before printing the credentials-cleared message in handleReset
2026-09-21 Make /reset (erase WiFi credentials) POST-only with a confirmation prompt
    [RaceDisplayV2.ino]
2026-09-21 Update parts list (battery, power switch, USB-C pass-through, buttons)
2026-09-21 Add button timing details to the README buttons table
2026-09-21 Make the buttons edge-triggered so taps act immediately and never get lost
2026-09-21 Show the heat banner as "Heat N" instead of "HEAT #N"
2026-09-21 Rename the sketch to RaceCounter, title the web pages "RotorHazard Race Counter", add FW_VERSION
2026-09-21 Refactor the sketch into .h/.cpp modules: display, web, wifi_config, buttons
2026-09-21 Add an information screen on a 3 s both-buttons hold, and show the firmware version on status screens
2026-09-21 Follow a RotorHazard timer over its Socket.IO connection (heat name and next round)
2026-09-21 Show the following round as soon as a race is stopped on the timer
2026-09-21 Show PRACTICE for a practice race format as well as for the timer's Practice Mode
2026-09-21 Accept a RotorHazard server address with a leading http:// or https://
2026-09-21 Save page: stop echoing the SSID and password, add a button back to the main page
2026-09-21 Main page: show what the panel is displaying, with a Refresh button
2026-09-21 Add the MIT license, with the RotorHazard name and logo under RotorHazard's own terms
2026-09-21 Detect a lost connection to the timer from its heartbeat and show it on the panel and web page
2026-09-21 Notice heat renames by re-fetching the heat name on each update; version 3.0.2
2026-09-22 Get heat and format names over the socket, falling back to /api (permanently after an oversized frame); version 3.0.3
2026-10-08 Add 3D-printed housing STLs and document the enclosure and its color scheme
    [Race Counter Back r3.stl, Race Counter Base r2.stl, Race Counter r2.stl]
2026-11-01 Require 5-second hold of buttons to clear WiFi settings
2026-11-01 Give up connecting after 5 minutes and wait for a button press, version 3.0.6
